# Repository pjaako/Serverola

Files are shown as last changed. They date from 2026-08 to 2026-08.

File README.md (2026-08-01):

# What is Serverola?
Serverola is a home server that blends into the living room interior camouflaging itself as a standard living room appliance.
## So, Serverola is just another PC in an amplifier case?
Yes and no. On one hand, it is a PC in an amplifier case, on another hand, it is still a fully functioning integrated amplifier, plus any functionality one can get from the amp+computer duo.

## How is it possible to shove PC hardware into an amp without disturbing the amp hardware?
It is not. Well, not in the case of Onkyo A-8220 amplifier, which is my case. Forty-year-old A/B class audio boards had to go to give way to an ASRock N100DC-ITX motherboard (Intel N100, two SATA connectors, a DDR4 DIMM slot and a PCIe 3.0 x4 slot), two 3,5" HDDs and  modern Class D amplifier hardware. The only exception is the original japanese passive Baxandall circuit board, since it is the most efficient way to retain original tone and volume controls and keep their functionality too.

## Why anybody would do this?
I don't know. For me, it was the following:
- High WAF due to the virtue of not looking as a piece of rack-mounted IT stuff
- Saving scarce and precious space under the TV with a 2-in-1 solution.
- Full control and upgradeability at both hardware and software levels
- A DIY audio that looks better than 99% of DIY projects
- A lot of fun and experience through messing things up and making every possible mistake

## Isn't it cheaper and easier to by a nice HTPC case or the whole NAS/miniserver?
Yes, it is. However, the solutions I know of do not check one ore more boxes in the least above. They are either ugly, or vendor-locked, or not safe, or too weak, or all of the above. I use to have a  QNAP “silent" NAS. No, it wasn't silent. It just didn't have fans, which is not enough. No proper HDD damping + IronWolf drives “health-checking” forever made the noisy barely bearable. It wasn’t powerful (good luck running containers on 2 GB of RAM), and got [wave](https://www.qnap.com/static/landing/2021/qlocker/response/en/) after [wave](https://www.qnap.com/en/security-advisory/qsa-22-21) of ransomware incidents. Still, it looked less ugly than other solutions and I kept putting up with it until the [Intel LPC clock bug](https://www.reddit.com/r/qnap/comments/klbogi/warning_many_qnap_nas_are_dying_due_to_a_cpu_bug/) bricked it and I had to jump through hoops to rescue my data. That was the birthday of Serverola.

# Why does Serverola got a public repo?
I know all too good I need to document everything to make my Serverola remotely maintainable in a year, and a git repository is fine to store the details. However good a reason that can be, it is often not enough a motivation for a human being. I hope a semi-public status will work as a commitment device. Besides, a public repo is free on GitHub.

## What does the Serverola repository contain?
- BOMs to reorder parts for repairs (the most important part)
- 3D Models to not start from scratch when I need a bigger case
- Schematic diagrams for custom wiring I made. 
- A log as a kind of comments, which are crucial not only for the SW development.

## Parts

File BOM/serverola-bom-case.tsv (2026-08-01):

Line | What | What for | What I Bought | Qty | Where I Bought It | What I paid (EUR) | Comment
1 | Old, amplifier with aesthetics I like | Case with 80’s vibe | TECHNICS SU-Z25 (defunct) | 1 | ebay.de | 30 | _
2 | Mounting frame for 2 x 3,5” HDDs | Mount my HDDs inside the case | PHANTEKS HDD Mounting Frames, 2x 3,5", Stackable | 1 | amazon.de | 11 | _
3 | 150 x 150 x 0,25 mm Thermal Pad, one side adhesive | HDD cooling and vibration damping | T-Global GT10D-150-150-0.25-1A | 1 | DigiKey 1168-GT10D-150-150-0.25-1A-ND | 5 | _
4 | 35 x 35 x 0,25 mm Thermal Pad, both sides adhesive | HDD cooling and vibration damping | 3M 8810SQ-35(100) | 4 | Digikey 1067-8810SQ-35(100)-ND | 5 | _
5 | 25 x 240 x 1 mm Thermal Pad, one side adhesive | HDD cooling and vibration damping | 3M 5590H | 1 | TME 3M-5590-25-240-1.0 | 5 | _
6 | Hexagonal polyurethane foam bumpers, 11 x 3 mm | New feet for the amp | 3M SJ-5201-LIGHT-BROWN | 132 | Digikey 3M157589-ND | 7 | _
7 | Very strong double sided adhesive film | Fasten parts without screws | 3M 5981-035-4-11 | 1 | Digikey 1067-5981-035-4-11-ND | 5 | 4.00" X 11.00" (100 x 280 mm) VHB sheet, ~0.5mm thick
8 | IDC connectors 10 positions | Wiring power switch, audio, maybe USB | Würth Elektronik 61201023021 | 4 | Digikey 732-2102-ND | 1 | _
9 | Ribbon cable | Wiring power switch, audio, maybe USB | 3M 3302/50 100, ft. | 2 | Digikey 19-3302/50100-DS-ND | 10 | 50 conductors zippable cable, will suffice for all wiring
10 | Polarising key for IDC connectors | Always plug connectors right the 1st time | Harwin M20-003 | 10 | Digikey 952-2360-ND | 2 | _
11 | Plastic standoffs, M3 x 11 mm | Attach the motherboard to mounts | Essentra MTNSP-M3-11-1 | 3 | DigiKey MTNSP-M3-11-1-ND | 4 | Non-conductive to avoid multiple ground points
12 | Brass standoff, M3 x 11 mm | Attach the motherboard to mounts | Würth Elektronik 970110324 | 2 | DigiKey 732-12849-ND | 1 | Conductive to provide reliable grounding point (which IO shield is not)

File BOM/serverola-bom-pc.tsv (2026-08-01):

Line | What | What for | What I Bought | Qty | Where I Bought It | What I paid (EUR) | Comment
1 | ITX Motherboard with barrel (”DC”, ”brick”) connector | Server part | ASROCK N100DC-ITX | 1 | alza.de | 125 | _
2 | DDR4 Module | Server part | SK Hynix 16GB DDR4-3200 (used) | 1 | ebay.de | 20 | should have gone with 32Gb from the beginning, who knew it was gonna get THAT expensive...
3 | NVMe Drive | Server part | WD Black SN7100 (500 GB, M.2 2280) | 1 | galaxus.de | 51 | should do it for <10 VMs
4 | 3,5” HDDs | NAS | Seagate ST12000DM0007 BarraCuda Pro + 12TB 3,5” 256MB Cache (recertified) | 2 | ebay.de | 228 | not exactly a NAS model but the price for the recertified drives was too good (bought before the scam wave)
5 | 35mm high 140x140mm fan | Good airflow at minimal RPM | CORSAIR RS140 MAX 140mm | 1 | amazon.de | 12 | 30mm thick fan should suck in enough fresh cold air even at minimal RPM
6 | 2,5Gbps PCIe network card | Faster networking and passthrough to a VM | Intel I226T1 | 1 | 25n.de | 51 | I see no value in investing in a 10Gb switch at current price
7 | CNVio Wi-Fi/BT card | My workbench has no wired connection... | no-name AX211NGW CNVio2 | 1 | amazon.de | 35 | _
8 | 19V powerbrick not less than 100W | Powering all of the above and more | Delta SADP-135EB 19V 7A (used) | 1 | ebay.de | 10 | _

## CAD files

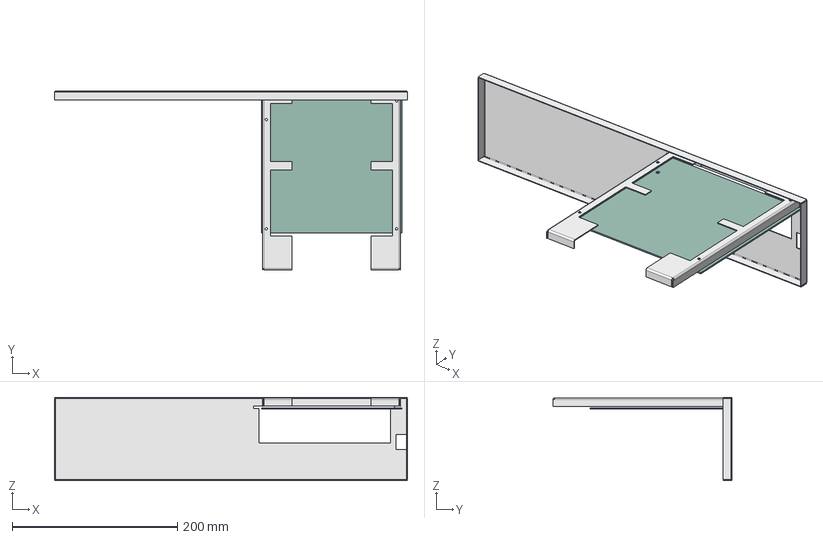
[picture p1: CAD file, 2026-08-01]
3D/Serverola Assy.step
427.0 x 216.8 x 101.0 mm
ITX Motherboard v5
Serverola-86 back plate
Serverola-86 motherboard bracket
Serverola-86 motherboard bracket (1)

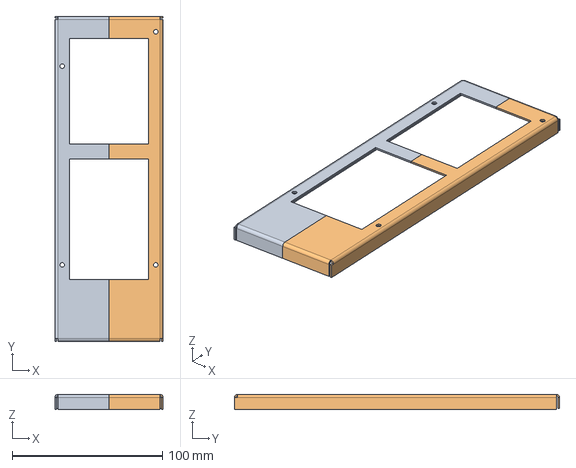
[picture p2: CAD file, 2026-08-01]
3D/Serverola motherboard brackets.step
72.0 x 216.0 x 10.2 mm

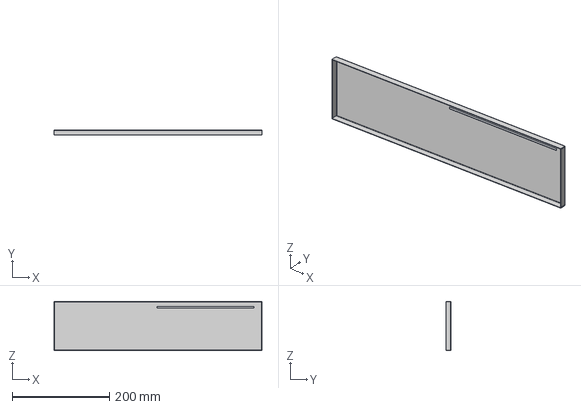
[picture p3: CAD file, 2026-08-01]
3D/Serverola back plate.step
427.0 x 11.0 x 101.0 mm

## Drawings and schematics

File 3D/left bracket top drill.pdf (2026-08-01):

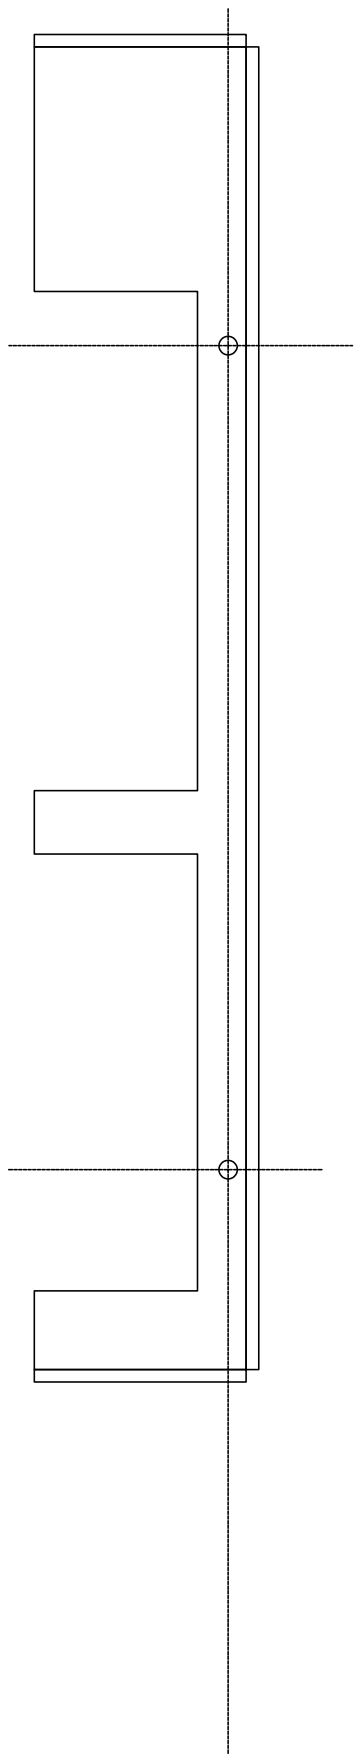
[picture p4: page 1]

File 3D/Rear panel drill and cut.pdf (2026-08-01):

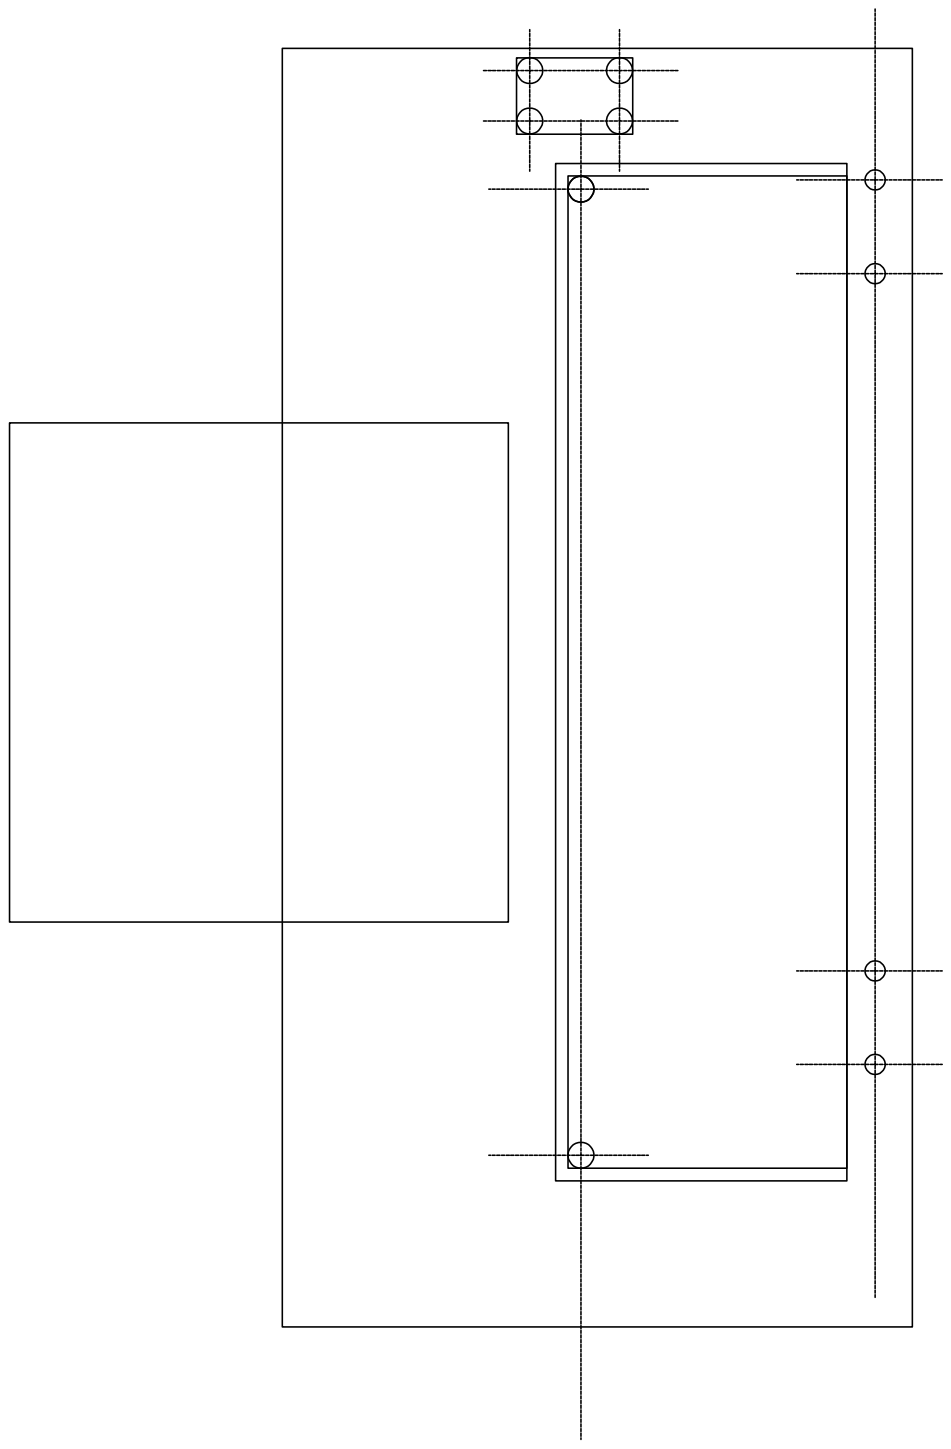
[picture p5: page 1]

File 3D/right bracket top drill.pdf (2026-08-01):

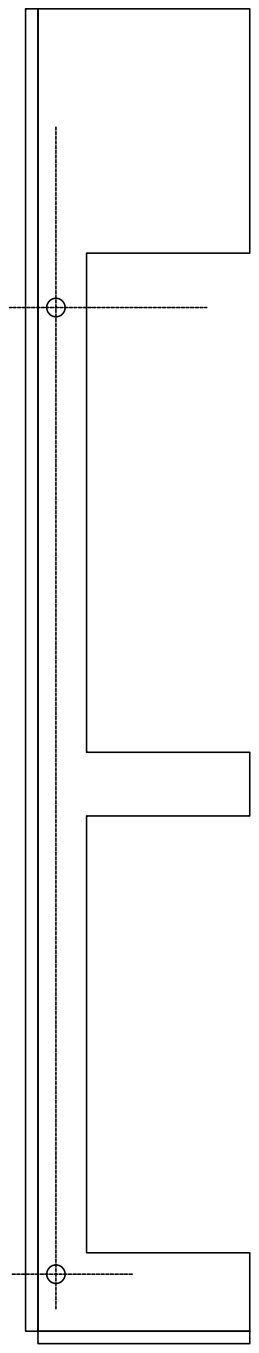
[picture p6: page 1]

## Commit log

2026-08-01 cleaning irrelevant 3D files'
    [ATX Constraints.f3d, ATX IO Shield and aperture.f3d, ITX Motherboard.f3d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]
2026-08-01 renaming project ProxVox->Serverola, now for 3D files
    [Serverola Assy.step, Serverola motherboard brackets.step, Servetola back plate.step]
2026-08-01 filename typo fix
    [Serverola back plate.step]
2026-08-01 renamed BOM files ProxVox->Serverola
    Last ProxVox remnants in the tree; one project name everywhere.
    [serverola-bom-case.tsv, serverola-bom-pc.tsv]
